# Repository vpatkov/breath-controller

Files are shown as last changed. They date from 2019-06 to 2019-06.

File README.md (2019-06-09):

# USB-MIDI Breath Controller

A device that converts breath pressure to MIDI data.

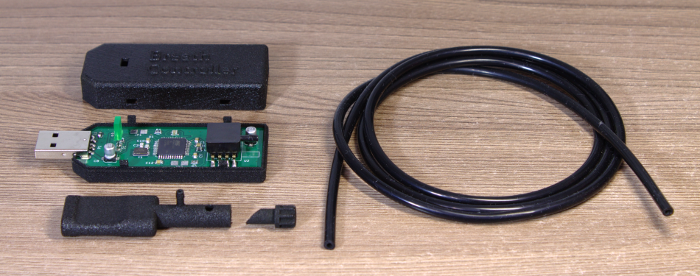
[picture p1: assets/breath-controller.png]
Breath Controller


The mouthpiece has an adjustable valve for drain control.

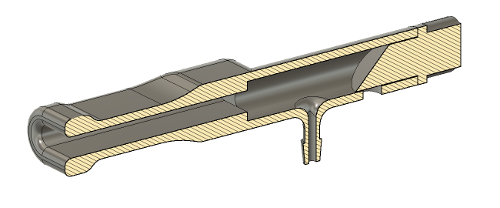
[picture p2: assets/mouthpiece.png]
Mouthpiece


The LED's brightness is proportional to the output MIDI value.
Until the USB interface is successfully configured the LED is fully on.

During initialization, the auto-zeroing of the pressure sensor
is performed. So, don't blow into the mouthpiece when
plugging the device.

The mouthpiece and the case are 3D printed from STL files
in the `3d` directory. The silicone tube is 4 mm OD and 2 mm ID.

## Software

By default, the device sends the pressure data as CC2
messages on channel 1, with maximal input and output ranges,
and linear response. These settings can be changed using the
configuration tool (in the `software` directory).

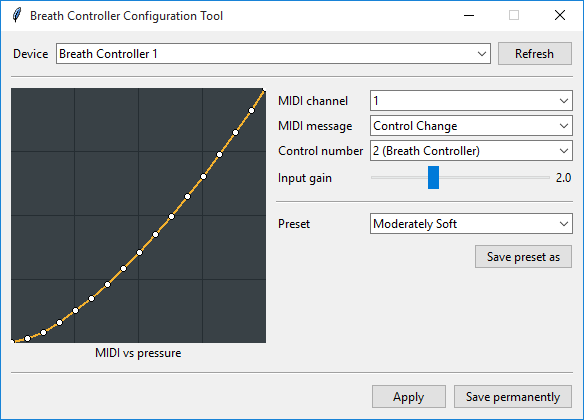
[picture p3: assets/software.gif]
Software


The response curve can be edited by mouse: the left button
adds and drags points, the right button removes them, and the
middle button resets the curve to default. The curve can
be arbitrary.

The input gain is applied before the curve.

Settings can be applied to the device temporary (until power
is removed) or saved permanently (in EEPROM).

The software works on Windows and Linux (both tested), and
should work on macOS.

## Technical details

The device is implemented with ATmega16U4 MCU and
MPXV4006GP pressure sensor. The MCU has hardware USB controller,
ADC, EEPROM, and other peripherals, eliminating the need of additional
chips. In firmware, [LUFA](http://www.lufa-lib.org) USB stack is used.

The pressure is sampled by ADC, averaged for 8 ms, applied auto-zero,
input gain, the response curve, and then is sent to the
host if the value differs from the previously sent one.

The response curve is implemented by a 128-byte lookup table. 
It's simple and allows arbitrary curves.

The runtime configuration is implemented with SysEx messages (see below)
from the host. The configuration tool is written in Python using
[MIDO](https://mido.readthedocs.io) and Tkinter libraries.

### SysEx messages to configure the device

- Set the MIDI channel: `F0 7D 00 XX F7` where `XX` is a MIDI
channel (1..16).

- Set the MIDI message: `F0 7D 01 XX F7` where `XX` is `00` for Control Change,
`01` for Channel Pressure, `02` for Pitch Bend Up, `03` for Pitch Bend Down.

- Set the control number: `F0 7D 02 XX F7` where `XX` is a control number (0..127).

- Set the input gain: `F0 7D 03 XX F7` where `XX` is input gain multiplied
by 10. `XX` must be in range 10..40.

- Set the response curve: `F0 7D 04 X0 X1 ... X127 F7` where
`X0 X1 ... X127` is a 128-byte lookup table. Each `Xn` must be in the range 0..127.

- Save current settings to EEPROM: `F0 7D 05 F7`.

### Preset file format

Presets used by the configuration tool are just plain text files
containing following lines:

- `midi_channel` followed by a decimal number (1..16);
- `midi_message` followed by a `control_change`, `channel_pressure`, `pitch_bend_up`,
or `pitch_bend_down`;
- `control_number` followed by a decimal number (0..127);
- `input_gain` followed by a floating point decimal number
(between 1.0 and 4.0);
- `curve` followed by a space delimited list of points `(x,y)`
where `x` and `y` are decimal numbers (0..127), assuming
linear interpolation between the points.

You can ignore some of the settings, they will not changed after loading the
preset. For example, you can create curve-only presets.

Preset must have `.preset` file extension and lie in the
`software/presets` directory.

## Programming

ATmega16U4-AU is shipped with a pre-installed USB bootloader and can be
programmed with the official
[FLIP](https://www.microchip.com/DevelopmentTools/ProductDetails/PartNO/FLIP)
software or [dfu-programmer](https://dfu-programmer.github.io/). To enter the
bootloader short HWB pin to GND during reset (there are screwdriver-compatible
pads for that on the PCB). Just in case, the PCB has pogo-compatible pads for
ISP programming. The fuses are factory default.

## License

Unless otherwise noted, this work is licensed under Creative Commons Zero 1.0.



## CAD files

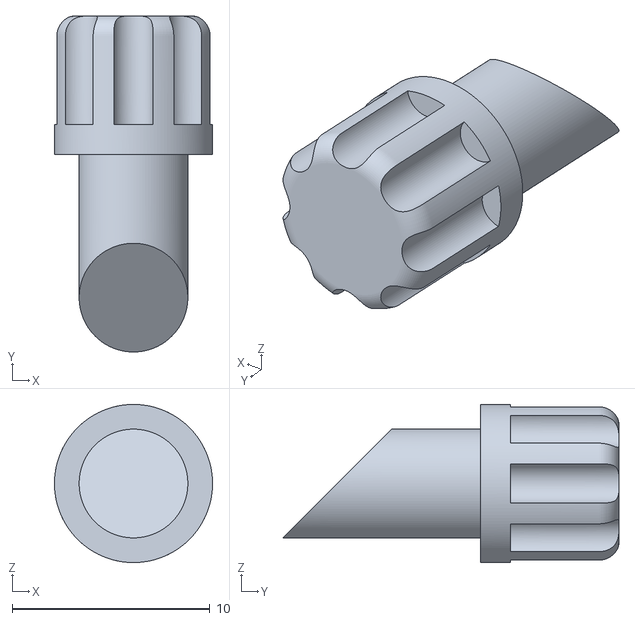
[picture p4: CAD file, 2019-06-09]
3d/cap.stl
8.00 x 17.0 x 8.00

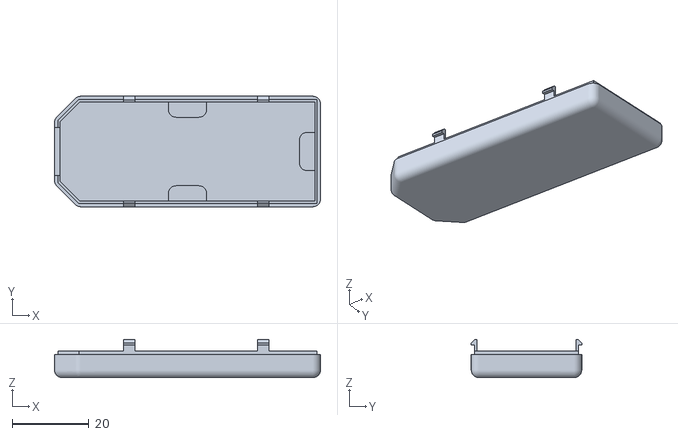
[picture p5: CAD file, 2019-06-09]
3d/case-bottom.stl
69.5 x 28.9 x 10.0

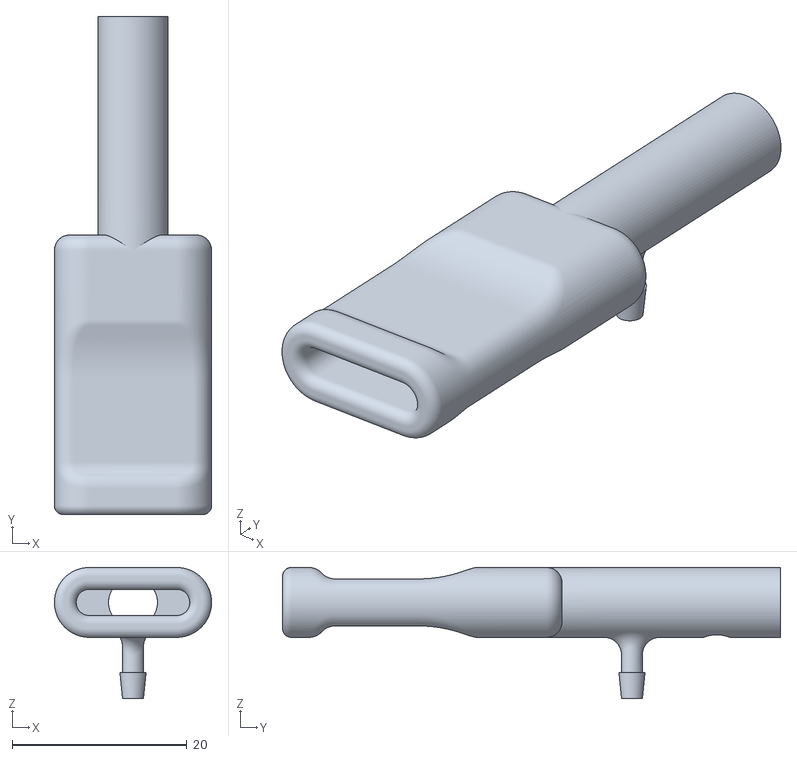
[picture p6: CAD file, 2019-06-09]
3d/mouthpiece.stl
18.0 x 57.0 x 15.0

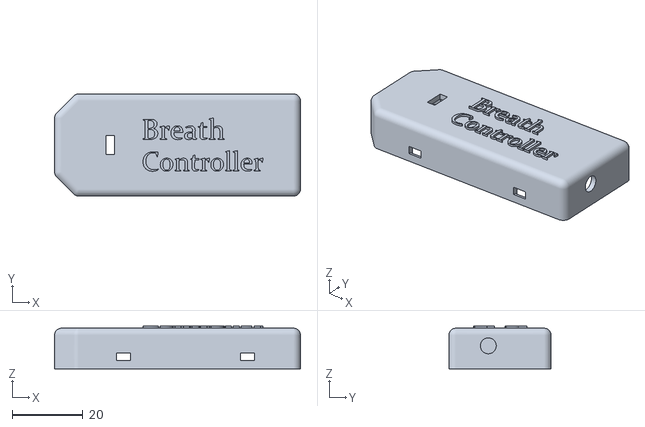
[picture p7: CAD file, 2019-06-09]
3d/case-top.stl
69.5 x 28.9 x 12.1

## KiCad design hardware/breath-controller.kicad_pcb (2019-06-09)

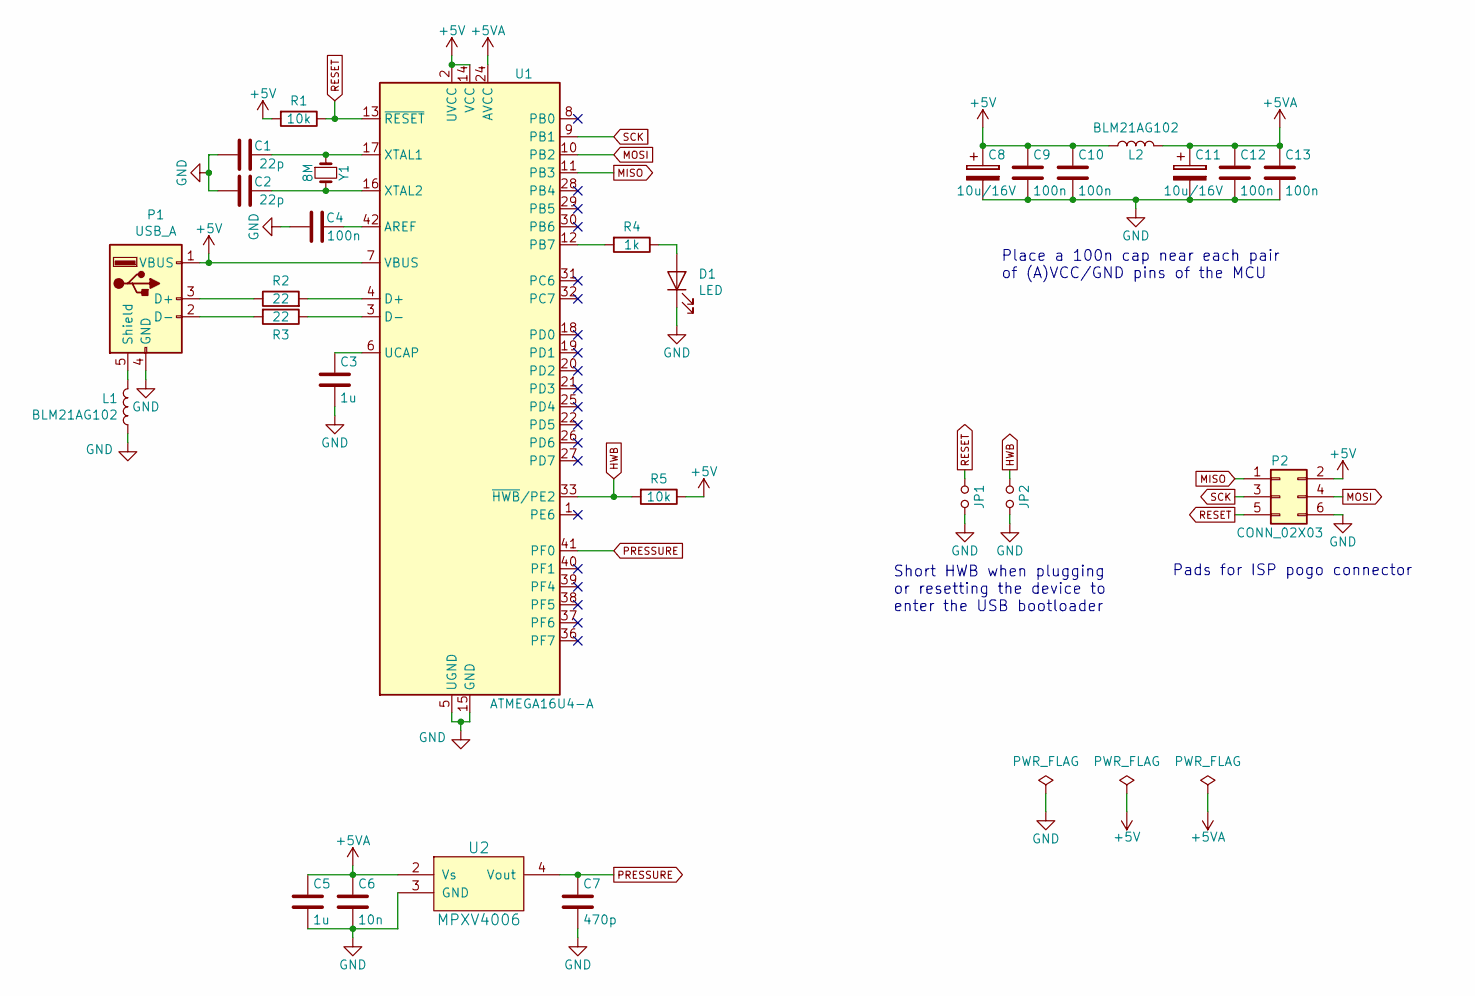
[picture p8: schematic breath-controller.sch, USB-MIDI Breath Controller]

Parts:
C1, C2: 22p; C_0805
C3, C5: 1u; C_0805
C4, C9, C10, C12, C13: 100n; C_0805
C6: 10n; C_0805
C7: 470p; C_0805
C8, C11: 10u/16V; c_elec_4x5.3
D1: LED; LED_2X5
JP1, JP2: Jumper_NO_Small; JUMPER_PADS
L1, L2: BLM21AG102; R_0805
P1: USB_A; USB_A_4UCON_10016
P2: CONN_02X03; POGO_AVR_ISP6
R1, R5: 10k; R_0805
R2, R3: 22; R_0805
R4: 1k; R_0805
U1: ATMEGA16U4-A; TQFP-44_10x10mm_Pitch0.8mm
U2: MPXV4006; MPXV4006GP
Y1: 8M; CRYSTAL_5032_2PIN

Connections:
+5V: C8.1, C9.1, C10.1, L2.1, P1.1 (VBUS), P2.2, R1.2, R5.1, U1.2 (UVCC), U1.7 (VBUS), U1.14 (VCC), U1.34 (VCC)
+5VA: C5.1, C6.1, C11.1, C12.1, C13.1, L2.2, U1.24 (AVCC), U1.44 (AVCC), U2.2 (Vs)
GND: C1.2, C2.2, C3.2, C4.2, C5.2, C6.2, C7.2, C8.2, C9.2, C10.2, C11.2, C12.2, C13.2, D1.1 (K), JP1.2, JP2.2, L1.1, P1.4 (GND), P2.6, U1.5 (UGND), U1.15 (GND), U1.23 (GND), U1.35 (GND), U1.43 (GND), U2.3 (GND)
HWB: JP2.1, R5.2, U1.33 (~HWB~/PE2)
MISO: P2.1, U1.11 (PB3)
MOSI: P2.4, U1.10 (PB2)
unnamed: C1.1, U1.17 (XTAL1), Y1.1
unnamed: C2.1, U1.16 (XTAL2), Y1.2
unnamed: C3.1, U1.6 (UCAP)
unnamed: C4.1, U1.42 (AREF)
unnamed: D1.2 (A), R4.1
unnamed: L1.2, P1.5 (Shield)
unnamed: P1.2 (D-), R3.2
unnamed: P1.3 (D+), R2.1
unnamed: R2.2, U1.4 (D+)
unnamed: R3.1, U1.3 (D-)
unnamed: R4.2, U1.12 (PB7)
PRESSURE: C7.1, U1.41 (PF0), U2.4 (Vout)
RESET: JP1.1, P2.5, R1.1, U1.13 (~RESET)
SCK: P2.3, U1.9 (PB1)

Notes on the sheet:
Place a 100n cap near each pair of (A)VCC/GND pins of the MCU
Pads for ISP pogo connector
Short HWB when plugging or resetting the device to enter the USB bootloader

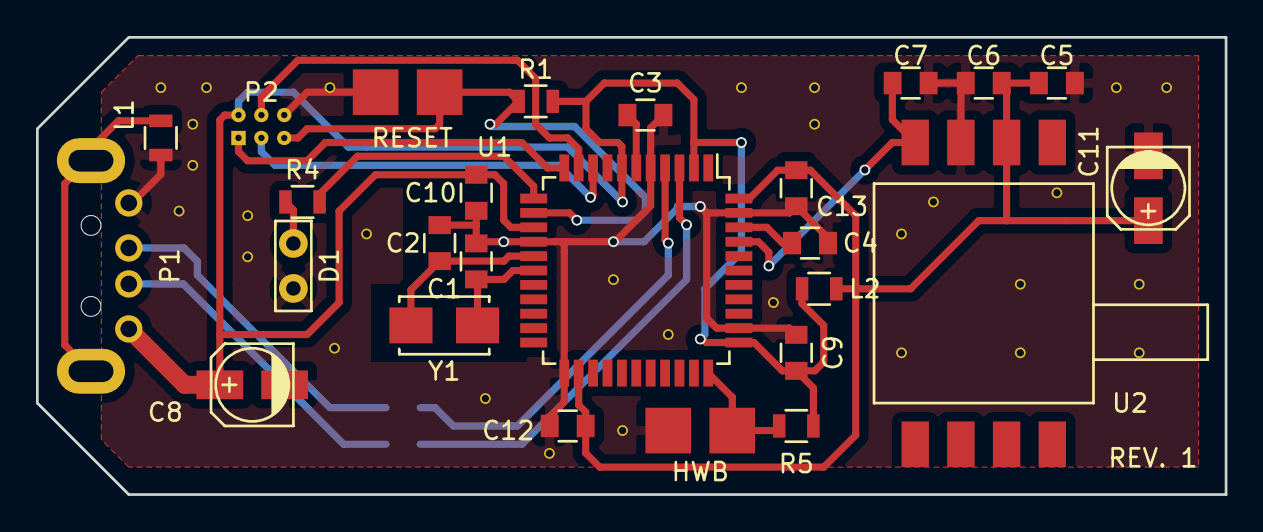
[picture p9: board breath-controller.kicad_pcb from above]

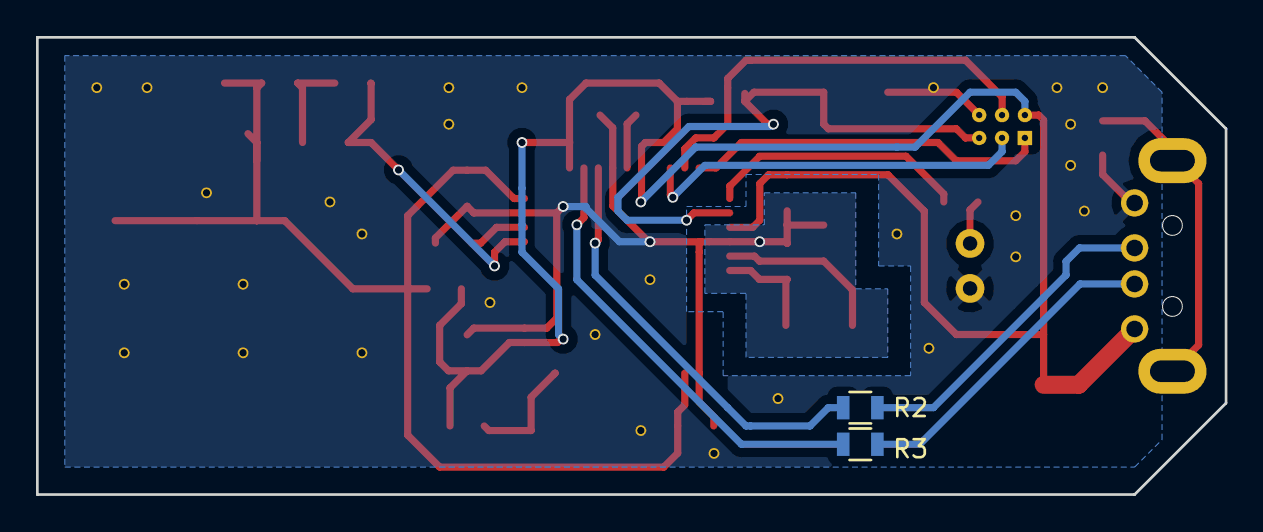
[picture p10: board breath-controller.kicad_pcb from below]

Board: 2 copper layers, 66.0 x 25.4 mm, 28 parts (2 on the bottom side), 20 nets.

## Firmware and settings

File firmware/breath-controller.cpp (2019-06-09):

/* Main program */

#include <stdint.h>
#include <stddef.h>
#include <avr/io.h>
#include <avr/interrupt.h>
#include <avr/eeprom.h>
#include <lufa/Drivers/USB/USB.h>
#include "descriptors.h"
#include "shared.hpp"
#include "common.hpp"
#include "delay.hpp"

/* Peripherals are configured for 8 MHz system clock */
static_assert(F_CPU == 8e6, "");

constexpr uint8_t pressure_adc_channel = 0;
constexpr uint8_t sysex_id = 0x7d;      /* SysEx Manufacturer ID */

enum class MidiMessage: uint8_t {
        control_change,
        channel_pressure,
        pitch_bend_up,
        pitch_bend_down,
};

enum class SysExCommand: uint8_t {
        set_midi_channel,
        set_midi_message,
        set_control_number,
        set_input_gain,
        set_curve,
        save_to_eeprom,
};

struct Settings {
        uint8_t midi_channel;           /* MIDI channel (1..16) */
        MidiMessage midi_message;       /* MIDI message */
        uint8_t control_number;         /* Control number (0..127) */
        uint8_t input_gain;             /* Input gain multiplied by 10 (10..40) */
        uint8_t curve[128];             /* Pressure (0..127) -> MIDI value (0..127) */
} __attribute__((packed));              /* Pack because we'll put it in EEPROM */

static Settings settings;

/* EEPROM */
Settings ee_settings EEMEM = {
        .midi_channel = 1,
        .midi_message = MidiMessage::control_change,
        .control_number = 2,
        .input_gain = 10,
        .curve = {
                  0,   1,   2,   3,   4,   5,   6,   7,
                  8,   9,  10,  11,  12,  13,  14,  15,
                 16,  17,  18,  19,  20,  21,  22,  23,
                 24,  25,  26,  27,  28,  29,  30,  31,
                 32,  33,  34,  35,  36,  37,  38,  39,
                 40,  41,  42,  43,  44,  45,  46,  47,
                 48,  49,  50,  51,  52,  53,  54,  55,
                 56,  57,  58,  59,  60,  61,  62,  63,
                 64,  65,  66,  67,  68,  69,  70,  71,
                 72,  73,  74,  75,  76,  77,  78,  79,
                 80,  81,  82,  83,  84,  85,  86,  87,
                 88,  89,  90,  91,  92,  93,  94,  95,
                 96,  97,  98,  99, 100, 101, 102, 103,
                104, 105, 106, 107, 108, 109, 110, 111,
                112, 113, 114, 115, 116, 117, 118, 119,
                120, 121, 122, 123, 124, 125, 126, 127,
        },
};

/* Shared variables (changed in interrupts) */
static uint8_t s_pressure;              /* Current pressure from the sensor (0..255) */
static bool s_pressure_updated;         /* Sets to 1 when 's_pressure' is updated */

/* 4 kHz general-purpose interrupt */
ISR(TIMER1_COMPA_vect)
{
        /* Measure the pressure */
        {
                static uint8_t counter = 0;
                static uint16_t accumulator = 0;

                accumulator += ADCH;
                if (++counter > 31) {   /* Accumulate within 8 ms (125 Hz) */
                        s_pressure = accumulator/32;
                        s_pressure_updated = 1;
                        accumulator = 0;
                        counter = 0;
                }

                /* Start next conversiona (AVCC reference, 125 kHz clock) */
                static_assert(pressure_adc_channel <= 7, "");
                ADMUX = 1<<REFS0 | 1<<ADLAR | pressure_adc_channel;
                ADCSRA = 1<<ADEN | 1<<ADSC | 1<<ADPS2 | 1<<ADPS1;
        }
}

/* Process raw incoming SysEx message "F0 ... F7" */
static void process_sysex(const uint8_t *message)
{
        if (message[0] != 0xf0 || message[1] != sysex_id)
                return;

        switch (static_cast<SysExCommand>(message[2])) {
        case SysExCommand::set_midi_channel:
                settings.midi_channel = clamp<uint8_t>(message[3], 1, 16);
                break;
        case SysExCommand::set_midi_message:
                settings.midi_message = static_cast<MidiMessage>(message[3]);
                break;
        case SysExCommand::set_control_number:
                settings.control_number = min<uint8_t>(message[3], 127);
                break;
        case SysExCommand::set_input_gain:
                settings.input_gain = clamp<uint8_t>(message[3], 10, 40);
                break;
        case SysExCommand::set_curve:
                for (uint8_t i = 0; i < 128 && message[i+3] != 0xf7; i++)
                        settings.curve[i] = min<uint8_t>(message[i+3], 127);
                break;
        case SysExCommand::save_to_eeprom:
                eeprom_update_block(&settings, &ee_settings, sizeof(Settings));
                break;
        default:
                break;
        }
}

/* Receive SysEx messages from the host */
static void midi_receive()
{
        MIDI_EventPacket_t event;
        constexpr size_t sysex_buffer_size = 256;
        static uint8_t buffer[sysex_buffer_size], pos = 0;

        if (USB_DeviceState != DEVICE_STATE_Configured)
                return;

        Endpoint_SelectEndpoint(MIDI_STREAM_OUT_EPADDR);

        if (!Endpoint_IsOUTReceived())
                return;

        Endpoint_Read_Stream_LE(&event, sizeof(event), NULL);

        switch (event.Event) {
        case MIDI_EVENT(0, MIDI_COMMAND_SYSEX_START_3BYTE):
        case MIDI_EVENT(0, MIDI_COMMAND_SYSEX_END_3BYTE):
                if (sysex_buffer_size - pos >= 3) {
                        buffer[pos++] = event.Data1;
                        buffer[pos++] = event.Data2;
                        buffer[pos++] = event.Data3;
                }
                break;
        case MIDI_EVENT(0, MIDI_COMMAND_SYSEX_END_2BYTE):
                if (sysex_buffer_size - pos >= 2) {
                        buffer[pos++] = event.Data1;
                        buffer[pos++] = event.Data2;
                }
                break;
        case MIDI_EVENT(0, MIDI_COMMAND_SYSEX_END_1BYTE):
                if (sysex_buffer_size - pos >= 1)
                        buffer[pos++] = event.Data1;
                break;
        default:
                break;
        }

        if (buffer[pos-1] == 0xf7) {
                process_sysex(buffer);
                pos = 0;
        }

        if (Endpoint_BytesInEndpoint() == 0)
                Endpoint_ClearOUT();
}

/* Send MIDI data to the host */
static void midi_send(uint8_t value)
{
        static uint8_t previous_value;
        MIDI_EventPacket_t event;

        if (value == previous_value)
                return;

        if (USB_DeviceState != DEVICE_STATE_Configured)
                return;

        Endpoint_SelectEndpoint(MIDI_STREAM_IN_EPADDR);

        if (!Endpoint_IsINReady())
                return;

        switch (settings.midi_message) {
        case MidiMessage::control_change:
                event.Event = MIDI_EVENT(0, MIDI_COMMAND_CONTROL_CHANGE);
                event.Data1 = MIDI_COMMAND_CONTROL_CHANGE | MIDI_CHANNEL(settings.midi_channel);
                event.Data2 = settings.control_number;
                event.Data3 = value;
                break;
        case MidiMessage::channel_pressure:
                event.Event = MIDI_EVENT(0, MIDI_COMMAND_CHANNEL_PRESSURE);
                event.Data1 = MIDI_COMMAND_CHANNEL_PRESSURE | MIDI_CHANNEL(settings.midi_channel);
                event.Data2 = value;
                event.Data3 = 0;
                break;
        case MidiMessage::pitch_bend_up:
                event.Event = MIDI_EVENT(0, MIDI_COMMAND_PITCH_WHEEL_CHANGE);
                event.Data1 = MIDI_COMMAND_PITCH_WHEEL_CHANGE | MIDI_CHANNEL(settings.midi_channel);
                event.Data2 = ((value & 63) | (value << 6)) & 127;
                event.Data3 = (128 + value) >> 1;
                break;
        case MidiMessage::pitch_bend_down:
                event.Event = MIDI_EVENT(0, MIDI_COMMAND_PITCH_WHEEL_CHANGE);
                event.Data1 = MIDI_COMMAND_PITCH_WHEEL_CHANGE | MIDI_CHANNEL(settings.midi_channel);
                event.Data2 = ((-value & 63) | (-value << 6)) & 127;
                event.Data3 = (128 - value) >> 1;
                break;
        default:
                return;
        }

        Endpoint_Write_Stream_LE(&event, sizeof(event), NULL);
        Endpoint_ClearIN();

        previous_value = value;
}

/* Event handler for the USB_Connect event */
void EVENT_USB_Device_Connect(void)
{
}

/* Event handler for the USB_Disconnect event */
void EVENT_USB_Device_Disconnect(void)
{
}

/* Event handler for the USB_ConfigurationChanged event */
void EVENT_USB_Device_ConfigurationChanged(void)
{
        bool success = true;

        /* Setup MIDI Data Endpoints */
        success &= Endpoint_ConfigureEndpoint(MIDI_STREAM_IN_EPADDR, EP_TYPE_BULK, MIDI_STREAM_EPSIZE, 1);
        success &= Endpoint_ConfigureEndpoint(MIDI_STREAM_OUT_EPADDR, EP_TYPE_BULK, MIDI_STREAM_EPSIZE, 1);

        /* If success then LED's brightness is PWM controlled */
        set_bits(TCCR0A, 1<<COM0A1, success);
}

static uint8_t zero_adjust(uint8_t value, uint8_t zero)
{
        return (value > zero) ? (value-zero)*255u/(255u-zero) : 0;
}

static uint8_t input_gain(uint8_t value, uint8_t gain)
{
        return min(static_cast<uint16_t>(value)*gain/10u, 255u);
}

int main()
{
        /* Disable the system clock prescaler */
        CLKPR = 1<<CLKPCE;
        CLKPR = 0;

        /* Enable Watchdog Timer (1 s) */
        WDTCSR = 1<<WDCE | 1<<WDE;
        WDTCSR = 1<<WDE | 1<<WDP2 | 1<<WDP1;

        /* GPIO init */
        DDRB  = 0b10000000;
        PORTB = 0b11111111;
        DDRC  = 0b00000000;
        PORTC = 0b11111111;
        DDRD  = 0b00000000;
        PORTD = 0b11111111;
        DDRE  = 0b00000000;
        PORTE = 0b11111111;
        DDRF  = 0b00000000;
        PORTF = 0b11111110;

        /* T/C0: PWM for the LED */
        TCCR0A = 1<<WGM01 | 1<<WGM00;
        TCCR0B = 1<<CS01;
        OCR0A = 0;

        /* T/C1: 4 kHz general-purpose interrupt */
        TCCR1A = 0;
        TCCR1B = 1<<WGM12 | 1<<CS11;
        OCR1A = 249;
        TIMSK1 = 1<<OCIE1A;

        /* Disable unused peripherals */
        ACSR |= 1<<ACD;
        PRR0 = 1<<PRTWI | 1<<PRSPI;
        PRR1 = 1<<4 /* PRTIM4 */ | 1<<PRTIM3 | 1<<PRUSART1;

        /* Load settings from EEPROM */
        eeprom_read_block(&settings, &ee_settings, sizeof(Settings));

        USB_Init();

        sei();

        /* Skip transients */
        delay_ms(500);

        /* Auto-zero */
        uint8_t pressure_zero = atomic_read(s_pressure);

        while (true)
        {
                asm volatile ("wdr" ::: "memory");

                if (atomic_read(s_pressure_updated)) {
                        uint8_t v = atomic_read(s_pressure);
                        v = zero_adjust(v, pressure_zero);
                        v = input_gain(v, settings.input_gain);
                        v = settings.curve[v/2];
                        OCR0A = v*2;
                        midi_send(v);
                        atomic_write(s_pressure_updated, 0);
                }

                midi_receive();
                USB_USBTask();
        }

        return 0;
}
